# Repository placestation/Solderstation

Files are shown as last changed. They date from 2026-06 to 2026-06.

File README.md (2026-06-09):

# Solderstation

An open-source reflow oven controller.

The firmware in this repository runs on an ESP32-S3 with a 3.5" touch display
(PlatformIO + Arduino framework + LVGL): PID temperature control, selectable
reflow profiles, a live temperature graph, manual heater control, and a WiFi
web interface.

## Buy one

You can purchase the reflow oven here:
**https://www.placestation.in/products/reflow-oven?variant=55802498679153**

## Build & flash

This is a [PlatformIO](https://platformio.org/) project.

```bash
pio run                 # build
pio run -t upload       # flash to the board
pio device monitor      # serial console (115200 baud)
```

Target environment: `esp32s3_devkit` (see `platformio.ini`).

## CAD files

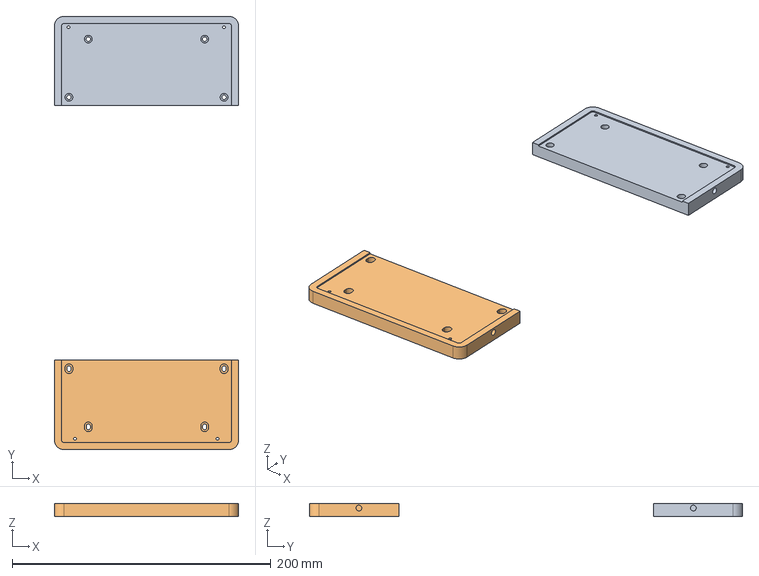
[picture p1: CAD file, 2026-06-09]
stl/pcb mount.step
142.6 x 335.0 x 10.0 mm

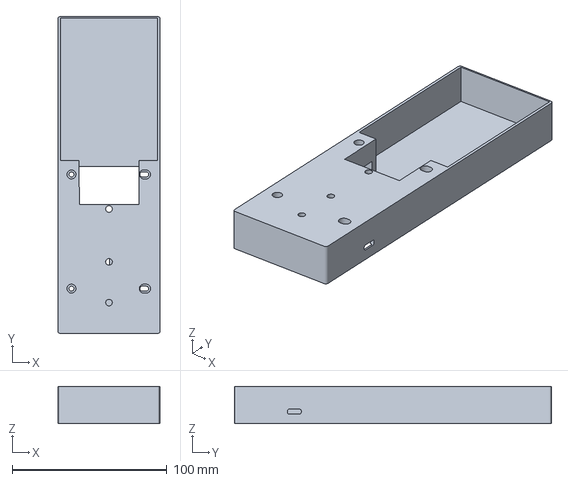
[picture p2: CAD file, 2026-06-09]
stl/Oven Front_thick.3mf
66.0 x 205.0 x 24.0 mm

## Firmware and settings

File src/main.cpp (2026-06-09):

#include <Arduino.h>
#include "esp_system.h"
#include "config.h"
#include "hardware.h"
#include "display.h"
#include "touch.h"
#include "reflow_logic.h"
#include "styles.h"
#include "ui.h"
#include "web_server.h"

uint32_t lvgl_last_tick = 0;
uint32_t lvgl_last_tick2 = 0;
uint32_t now;
uint32_t lvgl_task_handler_cb_period = 0;

void setup() {
    // Drive SSR pins LOW immediately on boot — before anything else
    // Prevents optocoupler leakage current during boot/init sequence
    pinMode(SSR1_PIN, OUTPUT);
    pinMode(SSR2_PIN, OUTPUT);
    digitalWrite(SSR1_PIN, LOW);
    digitalWrite(SSR2_PIN, LOW);

    // On cold power-on the USB peripheral can be left in an indeterminate
    // state. A software restart fixes it; subsequent boots come up as
    // ESP_RST_SW / ESP_RST_EXT so this only fires once per power cycle.
    if (esp_reset_reason() == ESP_RST_POWERON) {
        delay(200);
        esp_restart();
    }

    Serial.begin(115200);
    while (!Serial && millis() < 2000) {}
    Serial.println("=== Reflow Oven Controller Starting ===");

    initI2C();
    initTouch();
    // initExpander();
    initBacklight();
    customLcdReset();
    reflow_init();
    initDisplay();
    initLVGL();
    apply_app_styles(); // Must be after initLVGL()
    registerTouchInput();
    show_boot_screen(); // splash screen while rest of system inits
    create_ui();
    web_server_init();

    Serial.println("=== Setup Complete. System Ready. ===");
}

void loop() {    
    now = millis();

    if (now - lvgl_last_tick >= LVGL_TICK_PERIOD_MS) {
        lv_tick_inc(now - lvgl_last_tick);
        lvgl_last_tick = now;
    }

    if (now - lvgl_last_tick2 > lvgl_task_handler_cb_period) {
        lvgl_task_handler_cb_period = lv_task_handler();
        lvgl_last_tick2 = now;
    }

    reflow_loop();
    web_server_loop();

    delay(1); // yield to RTOS; lower than before to keep up with the faster refresh/touch cadence
}

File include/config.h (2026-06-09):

#ifndef CONFIG_H
#define CONFIG_H

#include <Arduino.h>

// --- WiFi Configuration ---
extern const char* WIFI_SSID;
extern const char* WIFI_PASSWORD;

// --- I2C pins for Waveshare display with WMCU ESP32-S3 devkit ---
#define I2C_SDA_PIN 8
#define I2C_SCL_PIN 7

//#define IO_EXPANDER_ADDR 0x20
#define LCD_RST 4
//#define EXPANDER_PIN_LCD_RST 10

// --- Waveshare ESP32 with 3.5" integrated touch display pins ---
// #define TFT_MOSI 1
// #define TFT_SCLK 5
// #define TFT_DC   3
// #define TFT_CS   12
// #define TFT_BL   6

// --- WMCU ESP32-S3 to display pins ---
#define TFT_MOSI 1
#define TFT_SCLK 5
#define TFT_DC   3
#define TFT_CS   39
#define TFT_BL   6

#define TP_RST 11
#define TP_INT 10

#define MAX6675_CLK 38
#define MAX6675_DO  21// 48 in personal
#define MAX6675_CS  16

#define SSR1_PIN 17
#define SSR2_PIN 18

// --- Screen & LVGL Settings ---
static const uint16_t screenWidth  = 320;
static const uint16_t screenHeight = 480;
#define LVGL_BUFFER_LINES 60   // larger draw buffer → fewer SPI flush round-trips (was 40)
#define LVGL_TICK_PERIOD_MS 5

#endif

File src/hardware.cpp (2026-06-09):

#include <Arduino.h>  // Add this at the top
#include "hardware.h"

//TCA9554 expander(IO_EXPANDER_ADDR, &Wire);

void initI2C() {
    Wire.begin(I2C_SDA_PIN, I2C_SCL_PIN);
    Wire.setClock(400000);   // 400 kHz (was 100 kHz) — faster touch polling, snappier buttons
    delay(50);
}

/*void initExpander() {
    if (!expander.begin()) {
        Serial.println("ERROR: IO Expander failed to initialize!");
        while (true) {
            delay(1000);
        }
    }
    Serial.println("IO Expander initialized");
    
    expander.pinMode1(EXPANDER_PIN_LCD_RST, OUTPUT);
    expander.write1(EXPANDER_PIN_LCD_RST, HIGH);
    delay(20);
}
*/
void initBacklight() {
    pinMode(TFT_BL, OUTPUT);
    digitalWrite(TFT_BL, HIGH);
    Serial.println("Backlight enabled");
}

void customLcdReset() {
    Serial.println("Performing LCD reset...");
    pinMode(LCD_RST, OUTPUT);  // make sure it's set as output
    digitalWrite(LCD_RST, HIGH);
    delay(10);
    digitalWrite(LCD_RST, LOW);
    delay(120);
    digitalWrite(LCD_RST, HIGH);
    delay(150);
    Serial.println("LCD reset complete");
}

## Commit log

2026-06-09 Initial backup: working Solderstation reflow controller firmware
    ESP32-S3 PID reflow oven / soldering station controller (PlatformIO,
    Arduino framework, LVGL 8 UI). Known-good build at time of backup.
    [Oven Front_thick.3mf, pcb mount.step]
2026-06-09 perf: speed up UI rendering and touch response
    - display: run ST7796 SPI at 80MHz (was 40MHz default) — ~2x faster frame
    push, the main fix for scroll frame drops and chart repaint clunkiness
    - touch: I2C clock 100kHz -> 400kHz for snappier button response
    - lvgl: LV_DEF_REFR_PERIOD 33 -> 16ms (~60fps, also halves touch-read latency)
    - display: LVGL draw buffer 40 -> 60 lines (fewer SPI flush round-trips)
    - loop: delay(2) -> delay(1) to keep up with the faster cadence
    All changes are conservative and reversible. main branch holds the known-good
    backup; this work is isolated on perf-optimization.
    [config.h, display.cpp, hardware.cpp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]
2026-06-09 docs: replace stale Waveshare-demo README with Solderstation README
    Add open-source reflow oven description and purchase link.
2026-06-09 fix: skip PREPARE when oven already hot; lighten display chart
    - reflow: clicking Start with temp >= PREPARE_TEMPERATURE_CUTOFF now skips
    the 45s PREPARE warm-up and begins the profile immediately. Previously a
    hot restart sat in "Preparing" with heaters off for 45s, appearing stuck.
    Implemented by backdating the timers so the existing time-based state
    machine resolves to PREHEAT at once.
    - ui: live temperature chart LV_CHART_TYPE_SCATTER -> LINE (data is written
    by index, so LINE renders identically but far cheaper) and init to
    POINT_NONE instead of a flat zero-line. Smoother/cleaner display graph.
    [reflow_logic.cpp]
2026-06-09 perf+ui: real 60fps, cached shadows, merged chart, too-hot guard
    Display smoothness (root cause found):
    - lv_conf.h is a v9 template but platformio pins LVGL 8.3.11, which reads
    LV_DISP_DEF_REFR_PERIOD / LV_INDEV_DEF_READ_PERIOD — names absent from the
    file, so it silently ran at the 30ms (30fps) defaults. Added the correct
    8.3 macros: 16ms refresh (~60fps) + 10ms touch read. (The earlier
    LV_DEF_REFR_PERIOD edit was a no-op; the touch win came from I2C 400kHz.)
    - Enabled LV_SHADOW_CACHE_SIZE: the 20px card drop-shadow was re-blurred for
    every card on every repaint (cache defaulted to 0) — a major scroll-jank
    source. Now cached once and reused.
    Graph:
    - Merged the two stacked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
    [reflow_logic.cpp]
2026-06-09 safety+pid+ui: thermocouple fault abort, PID re-init, power readout
    Safety (the big one — matches what Controleo3 guards):
    - Thermocouple fault detection. updateTemperature() previously froze the
    reading on NaN/<=0 and kept driving the heaters toward the profile — a
    runaway risk if the probe disconnects mid-reflow. Now N consecutive bad
    reads (~2.5s) trigger a safe abort (heaters off, IDLE) and a fault screen.
    - Generalised the fullscreen fault screen to show the reason (overheat vs
    thermocouple fault) via reflow_get_fault_string().
    PID correctness:
    - Re-initialise the PID when entering a controlled phase (PREHEAT/SOAK/REFLOW)
    from the non-PID phases, so the idle gap can't cau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
    [reflow_logic.cpp, reflow_logic.h]
2026-06-09 feat: temperature-gated profile clock (honour dwell times at temp)
    The profile previously advanced on wall-clock, so on a slow oven the soak and
    reflow dwell times were partly consumed catching up to the ramp — the board
    never actually sat at soak/peak for the full programmed duration.
    Now updateTargetAndState() advances a thermal-progress clock that PAUSES while
    a heating ramp (preheat or soak->reflow) lags the setpoint by more than
    PROFILE_LAG_BAND_C (5°C). So the clock only enters SOAK once the oven is at
    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
2026-06-09 feat: thermal-safety watchdog + align live chart to profile clock
    Safety watchdog (checkThermalSafety, runs each control tick during PREHEAT/
    SOAK/REFLOW):
    - Thermal runaway: aborts if temperature stays >30°C above the setpoint for
    ~3s (e.g. a welded-shut SSR that won't stop heating).
    - Heating stall: aborts if, over a 60s window, the oven is still >10°C below
    target and rose <3°C (dead element, failed-open SSR, or an open door).
    Both fail safe (heaters off, IDLE) and show a reason on the fault screen via
    the existing overheat/TC-fault path. Thresholds chosen to avoid false trips on
    a normal run; a capable oven never triggers them.
    Chart alignment:
    - The actual-temperature curve is n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
    [reflow_logic.cpp, reflow_logic.h]
2026-06-09 fix: re-baseline profile at start; exit PREPARE on cutoff (fixes false runaway)
    Two reported bugs shared one root cause. PREPARE ran a fixed 45s and the oven
    overshot the 45C cutoff (e.g. to 52C), while `ambient` was captured at the cold
    Start click (~20C). When PREHEAT began, the ramp setpoint started at the stale
    cold ambient while the oven was already ~52C, so:
    - it sat in PREPARE with target 45 and no graph (graph skips PREPARE), and
    - currentTemp(52) > targetTemp(20) + 30 tripped a FALSE thermal runaway.
    Fix:
    - PREPARE now ends as soon as currentTemp >= PREPARE_TEMPERATURE_CUTOFF (or the
    timeout), so it no longer sits/overshoots.
    - The profile re-baselines ambient = currentTemp a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
    [reflow_logic.cpp]
